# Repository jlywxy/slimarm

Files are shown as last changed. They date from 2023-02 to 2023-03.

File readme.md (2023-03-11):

# SlimARM Boards

The project is aiming to manufacture custom-made boards of ARM processors(specially-designed for specified usage, slim in dimension).<br>

Author: jlywxy(jlywxy@outlook.com)<br>
Document Version: 0.5<br>

- --

## Project Status
```
[ok]SlimARM Classic
----[ok]SlimARM Classic 2410
----[stall]SlimARM Classic 2416
[..]SlimARM Zero
----[..]SlimARM Zero AllWinner A20
----[  ]SlimARM Zero RK3368
[  ]SlimARM Fusion Zynq
```
Note: [..] means work doing.

- --

## Board Specification

* Note 1: see each board design in their directories when board design is done.<br>
* Note 2: all board are designed with proper PCB constraints, even SDR SDRAMs are tuned in length.<br>
* Note 3: for some boards using DDR3, KiCad may also be used for design without proper simulation like Altium/Cadence provided. The design will almost comply to the sigrity stuffs (constraints, impedance) as able when routing to reduce the factor of lack of simulation.
<br>
<br>
<br>
Boards:
* SlimARM Zero<br>
CPU <b>AllWinner A20/Rockchip RK3368</b><br>
A board with minimum ARM requirements with USB, SDIO and Wi-Fi. <br>
This is specified for "On-The-Go" Linux experience similar to the RaspberryPi.<br>

* SlimARM Fusion<br>
CPU <b>Xilinx XC7Z010-1CLG400</b><br>
The board for Linux and calculation acceleration combination usage, the PL part of Zynq 7000s is also fine for LCD display and video processor. It is especially designed for low cost and convenience, picking up only xc7z010 and ft2232hl on board.

* SlimARM Classic (EOL)<br>
CPU <b>Samsung S3C2410AL/S3C2416XH</b><br>
A board with minimum ARM requirements with only USB Device Port extended.<br>
This board is pointing to low cost, replacing the legacy project 'us3c ultra'.<br>
Current cost for SlimARM Classic 2410: 24 RMB approx. (S3C2410: 9, DRAM: 2, NAND: 4, PCB: 6, LDO/Caps/R/Xtals/...: 3 approx.)<br>
<b>Note: This part is EOL and not suitable for new design/manufacture.</b><br>

- --
## Misc
### Board Part-of-Project,SubPart-of-Project to Board-Part-Number maps

Part of Project|Sub Part of Project|Board Part Number
-|-|-
SlimARM Classic|SlimARM Classic 2410|slarm_cls_2410
||SlimARM Classic 2416|slarm_cls_2416
SlimARM Zero|SlimARM Zero AllWinner A20|slarm_z_awa20
||SlimARM Zero RK3368|slarm_z_3368
SlimARM Fusion|SlimARM Fusion Zynq|slarm_f_7z010

---
### Document Patch and Errata
* Changed project plan: SlimARM Zero has changed its CPU from RK3128 to RK3368, which has 0.8mm-pitch BGA for low-cost PCB manufactuing.
* Marked slimarm classic 2410 workaround state.
* Paused the process of part "slimarm classic 2416" due to PCB manufacturing problem taken by 0.65mm-pitch BGA design.<br>

patch above: jlywxy@2023.3.11<br>

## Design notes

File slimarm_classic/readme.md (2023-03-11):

# SlimARM Classic

This part of project is making board for "classic" ARM processors (Samsung S3C2410AL/S3C2416XH).<br>
Although these chips are out-dated in performance, their cost is ever lower than STM32s while having higher performance than them, making them fit for entry-level ARM developments.<br>

Project status:<br>
```
[ok]SlimARM Classic 2410 (slarm_cls_2410_v1r2)
[stall]SlimARM Classic 2416 (slarm_cls_2416)
```

*Warning: The workaround part of linux running on the board is in a stall state. Look into slarm_cls_2410's readme for detail.
- --
## Misc

### Document Patch and Errata
* Marked slimarm classic 2410 workaround state.
* Paused the process of part "slimarm classic 2416" due to PCB manufacturing problem taken by 0.65mm-pitch BGA design.<br>

patch above: jlywxy@2023.3.11<br>

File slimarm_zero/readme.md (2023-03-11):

# SlimARM Zero

This part of project is making board for low-cost Cortex-A ARM processors.<br>

Project status:<br>
```
[..]SlimARM Zero AllWinner A20 (slarm_z_awa20)
[  ]SlimARM Zero RK3368 (slarm_z_3368)
```
- --
## Misc

### Document Patch and Errata
(none)

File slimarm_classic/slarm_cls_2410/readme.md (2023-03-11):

# Slimarm Classic 2410: bare-metal code execution and Linux research on S3C2410AL

This project is making a minimum S3C2410AL core board to run bare-metal code and Linux.
<br><br>
Author: jlywxy(jlywxy@outlook.com)<br>
Document Version: 2.1<br>

- --

## Project Status

```
[ok]pcb manufacturation and verification
[ok]openocd and jtag configurations 
[ok]KeilMDK/IAR toolchain bare-metal code compiling
[ok]openocd connect and debug
[ok]startup assembly explained and general concepts for arm startup sequences
[ok]gnu toolchain bare-metal assembly compiling
[ok]pcb with flash and dram stable version(slimarm classic)
[ok]pcb gerber sharing
[ok]gnu toolchain(arm-none-eabi-) bare-metal c code compiling

[failed]writing simple usb device CDC communication program
[ok]crosstool-ng toolchain on macOS(arm-unknown-linux-gnueabi-) and u-boot compiling
[failed]running Linux onboard, debugging via USBD
```
- --

## Processor Overview

Samsung S3C2410AL-20:<br>
* 16/32-bit(Little Endian) ARM920T RISC Arch
* ARM/Thumb mode
* JTAG debug
* internal 4kB Boot RAM(Steppingstone for NAND flash booting)
* 16kB I-Cache and 16kB D-Cache, MMU
* NAND & SDRAM support
* 1.8v internal voltage supporting max FCLK 200MHz
* on-chip PLL
* watchdog Timer
* 272-FBGA package (0.8mm pitch)
* 3.3v multiplexed I/O ports
* more but not related features...
- --

## S3C2410 Fail Part Problems
The workaround part of linux running on the board is in a stall state, since none of the proper u-boot version is found for s3c2410 to use USB Device as a console interface. u-boot seems never supported s3c2410 USB Device. The transition for UDC codes from linux to u-boot is hard to do. <br>
The fatal problem for USBD unablility is resulting from the board that did not extend any UART ports for u-boot to print debug messages.<br>
Since the processor is too old (in performance and arch) nowadays and <b>lack of support</b>, this part of project is marked with EOL, and not designing and revising new boards with 2410.<br>
<b>The day the usb device stuff is able to run on slimarm classic 2410, only the day the project starts again.</b><br>
As a result, The whole project is putting more attention on those advanced processors, see part SlimARM Zero/Fusion.

- --
## Making the core board for S3C2410

Note: This project is now testing the new designed core board `slimarm classic 2410 v1r1` with:<br>
* 32 MBytes SDRAM(tuned line length)
* 32 MBytes NAND flash(used for nand boot)

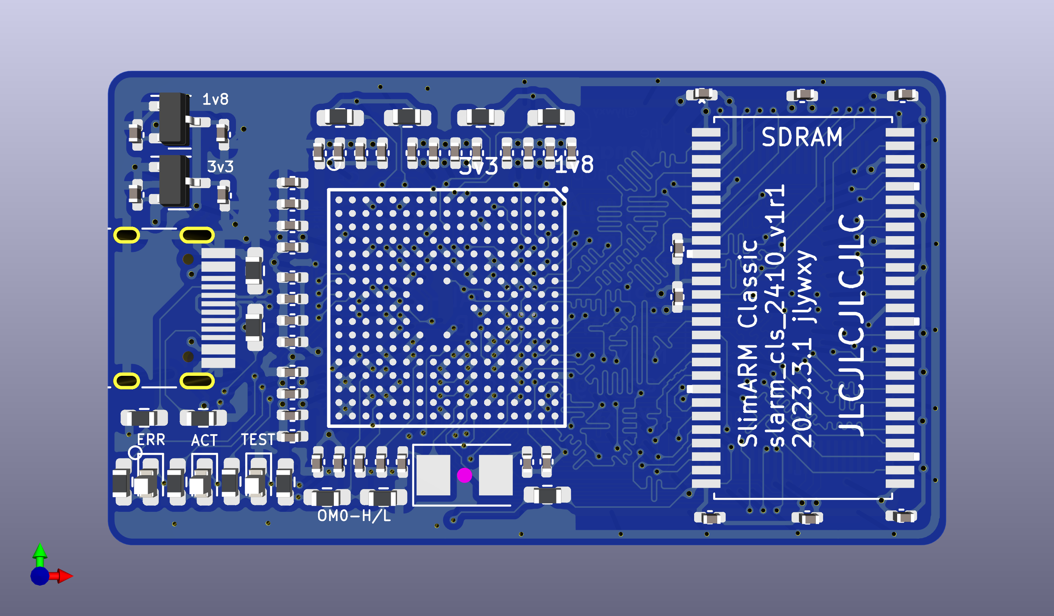
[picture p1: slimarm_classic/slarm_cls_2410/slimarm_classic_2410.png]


PCB Design Suggestions:
1. Make sure pins unwanted has been properly pulled-up or down according to S3C2410 datasheet.
2. When soldering S3C2410 onto the board, use heat gun <b>BELOW 300 C</b> temperature, otherwise the chip will damage.
3. When using 16 bit memory chips, connect chip address line A0 to CPU A1, and so on.
4. Enlarge the width of power lines as it could. Use 2.0v LDO instead of 1.8v LDO.
5. Satifsy "3W" wiring rule everywhere except of BGA area.
6. Make small components the same direction for easy soldering.

For more design points, see <a href="slimarm_classic_2410.md">slimarm_classic_2410.md</a>
- --

## Compiling LED-blinking code using arm-none-eabi- toolchain

1. Writing startup code<br>

* Init interrupt vectors<br>
* Jump to main (function of blinking LED)<br>
```asm
.text
    b _reset
    ldr pc, _undef
    ldr pc, _softir
    ldr pc, _abpre
    ldr pc, _abdat
    ldr pc, _reserved
    ldr pc, _irq
    ldr pc, _fiq
_reset:
    b main
```
https://stackoverflow.com/questions/18848776/what-does-label-word-label-mean-in-arm-assembly<br>

* Init arm modes and stacks(This part is still under working)<br>

Note: when loading 32bit immediate number to register, use `ldr Rn, =0xnum`:<br>
https://developer.arm.com/documentation/dui0473/j/writing-arm-assembly-language/load-32-bit-immediate-values-to-a-register-using-ldr-rd---const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<br>

2. Make and link

```shell
$ arm-none-eabi-as -mcpu=arm920t -o main.o main.s
$ arm-none-eabi-ld -T link.lds -o main.elf main.o
```
Note: the `.text` segment need to be linked to `0x40000000`. The linker script should look like this:<br>
```
SECTIONS {
    . = 0x40000000;
    .text : { * (.text); }
}
```
For the usage of linker script, check http://bravegnu.org/gnu-eprog/lds.html<br>

3. Check compiled executable in assembly and hex<br>
* Use arm-none-eabi-objdump to read startup code and c code assembly.<br>
```shell
$ arm-none-eabi-objdump -D /path/to/elf
```
Note: do not use objdump to read `.comment` section, use readelf instead.<br>
```shell
$ arm-none-eabi-readelf -p .comment /path/to/elf
```
* Use arm-none-eabi-objcopy to convert elf to hex(executable ihex,which represents the real binary stream content stored in memory chips), if another selected flash program is using hex files.<br>
```shell
$ arm-none-eabi-objcopy -O ihex /path/to/elf /path/to/hex
```

- --

## Connecting to the chip
1. This project uses a cheap cloned Altera USB Blaster as a JTAG programmer, because openocd has support for it and S3C2410 do not support SWD.

2. A custom openocd cfg file should be created.
checkout <a href="slimarm_classic_2410.cfg">slimarm_classic_2410.cfg</a>
- --

## Chip Boot Sequence

1. Before NAND takes place, OM[1:0] was set to 01 for not booting from NAND Flash and set Boot RAM bus width to 32bits. Simutaneously the address of Boot RAM is determined to 0x40000000.<br>Otherwise, the Boot RAM is linked to 0x0.
OM[3:2] was set to 00 to use Crystal(12MHz with two 22pF caps) for UPLL and MPLL clock input.

2. the Boot RAM (called as Steppingstone) is a piece of internal RAM region in the chip used for automatically copying boot code in NAND Flash to execute in place, which starts at 0x00000000. If ROM like NOR Flash is used, then the chip also starts at 0x00000000, fetching instructions from NOR directly.

3. When chip was powered on, it starts from Boot RAM or NOR (0x00000000), where interrupt vectors is set. Then it will <b>jump to the label for initializing each arm modes and their stack spaces, disabling IRQs, then environment is ready</b> to execute from c code `main`.<br>
https://developer.arm.com/documentation/dui0471/m/embedded-software-development/stack-pointer-initialization

- -- 

## Uploading compiled code to Boot RAM

1. Start openocd using previous created cfg file, connect to openocd CLI using telnet at port 4444. <br>
Then use openocd "load_image" command as follow:<br>
`load_image /path/to/elf(or axf or hex)`<br>
which means filling Boot RAM with selected program image.

2. start code execution:<br>
`resume 0x40000000`<br><br>
Note: when linker was not setting `.text` segment to correct address at 0x40000000, the program will not work.<br>
Because some of the constants are not calculated correctly based on the `.text` starting address. <br>
For more details, use `arm-none-eabi-objdump -d /path/to/elf` to differ the two compiled executives in <a href="link_problem_example">link_problem_example</a>, in where contains one elf linked `.text` to 0x0 and the other elf linked `.text` to 0x40000000.
In this environment, neither `b/bl :label/#num`,`ldr pc,[pc,#num]` nor `(openocd)resume #num` points real instruction address + 4. Use their real address when branching.

- --

## Misc

<--To Be Continued-->

1. Document Patch and Errata
* Added peripheral operation concepts in "Writing and Compiling code using Keil MDK 5"<br>
* Modified "BootROM" to "Boot RAM" in the whole article.<br>
* Added Boot RAM definition in "S3C2410AL Boot Concepts"<br>
* Added performance test method and knowledge bases in "Misc".<br>
* Added openocd init method and single-line-configuration(with arm machine code explained) in "Uploading compiled code to Boot RAM"<br>
* Corrected single-line-configuration, in which PLL conf command was set to more stable value. Corrected contents of machine code explained.
* Added paragraph "Processor Overview"<br>

patch above: jlywxy@2023.1.19<br>

* Added paragrapg "Project Status"<br>
* Modified "Connecting to the chip".2: added "bindto 0.0.0.0" for IAR remote gdb debug connection.<br>
* Modified "Writing and Compiling code using ~~Keil MDK 5~~ IAR 9" content for IAR usage.<br>
* Implemented "Processor Overview"<br>

patch above: jlywxy@2023.1.25<br>

* Modified Severe Error: in "Uploading compiled code to Boot RAM", after code loaded, openocd resuming from 0x40000000 rather than 0x40000004, which indicates a former linking problem: .text was linked to 0x0 and written to 0x40000000, therefore contents of constant data may be malformed. <br>

errata above: jlywxy@2023.1.26<br>

* Updated project status; adding PCB project files. <br>

patch above: jlywxy@2023.1.28<br>

* Changed the direction of the project.

patch above: jlywxy@2023.1.30<br>

* Modified PCB design problem. <br>
fixed sdram wiring problem; removed nor flash; added sdcard slot.

patch above: jlywxy@2023.2.5<br>

* Committed new PCB design and corrected PCB design points, corrected Chip boot concepts.

patch above: jlywxy@2023.3.1<br>

* Marked slimarm classic 2410 workaround state.

patch above: jlywxy@2023.3.11<br>

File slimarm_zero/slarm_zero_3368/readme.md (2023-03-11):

# SlimArm Zero 3368: The low-cost and slim board act as RaspberryPi

This part of project is making a 6-layer RK3368 standalone core board to run bare-metal code and Linux with a small dimension.
<br><br>
Author: jlywxy(jlywxy@outlook.com)<br>
Document Version: 1.0<br>

- --

## Project Status

```
[..]pcb design
----[  ]Circuit Schematics
----[  ]DDR3 wiring simulation by Candence
[  ]pcb manufacturation and verification
[  ]openocd and jtag configurations 
[  ]openocd connect and debug
[  ]pcb gerber sharing
....
```
- --

## Processor Overview

Rockchip RK3368:<br>
* 8x Cortex A53
* JTAG debug
* Internal 68KB SRAM
* SD/MMC/eMMC/NAND storage support
* DDR3 memory support
* 1.0/1.2/1.5/1.8/2.5/3.3 Voltage, DVFS
* on-chip PLL up to 2.2GHz
* TFBGA453 package <b>(0.8mm pitch)</b>
* more but not related features...
- --

<-- To Be Continued -->

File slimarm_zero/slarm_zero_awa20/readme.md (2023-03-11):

# SlimArm Zero AllWinner-A20: The low-cost and slim board act as RaspberryPi

This part of project is making a 4-layer AllWinner A20 standalone core board to run bare-metal code and Linux with a small dimension.
<br><br>
Author: jlywxy(jlywxy@outlook.com)<br>
Document Version: 1.0<br>

- --

## Project Status

```
[..]pcb design
----[..]Circuit Schematics
----[..]DDR3 wiring simulation by KiCad
[  ]pcb manufacturation and verification
[  ]openocd and jtag configurations 
[  ]openocd connect and debug
[  ]pcb gerber sharing
....
```
- --

## Processor Overview

AllWinner A20:<br>
* 2x Cortex A7
* JTAG debug
* SD/MMC/eMMC/NAND storage support
* DDR3 memory support
* 1.3/1.8/2.5/3.3 Voltage, DVFS
* on-chip PLL
* FBGA441 package <b>(0.8mm pitch)</b>
* more but not related features...
- --

<-- To Be Continued -->

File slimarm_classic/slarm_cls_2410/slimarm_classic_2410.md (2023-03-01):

# SlimARM Classic 2410 v1r1 PCB layout points

## PCB constraints

1. 4-layers
2. Line width: 3.5 mils
3. Line to Line/Via: 5+ mils
4. Minimum Via Diameter: 18 mils/10 mils

## BOM
```
Part No.                Package     Usage               Memory-Features     Brand      Comments

--Chip Components--
1. S3C2410AL-20:        FBGA272,    Main Processor,     4kB-SRAM            Samsung     3.3v+1.8v
2. HY57V561620FTP-H:    TSOPII54,   SDRAM,              32MB                Hynix       3.3v
3. K9F5608U0*:          TSOP48,     NAND Flash,         32MB                Samsung     3.3v
   MT29F1G08*           TSOP48,     NAND Flash,         128MB               Micron      3.3v

--Power Supply, Crystal, Connector Components--
1. XC6206:              SOT-23,     LDO,                -                   (Any)
2. (Any):               5032,       12MHz Crystal,      -                   (Any)       (with 22pF capacitors)
3. (Any):               USB-C-16p,  USB-C Connector,    -                   (Any)
```

## Wiring Notice

```
1. Cystal             12MHz + 22pF capacitor
2. EXTCLK             Pull-up (Not using EXTCLK)
3. nBATT_FLT          Pull-up (Not using Battery)
4. OM[3,2,1]          Pull-down (Not using EXTCLK)
5. JTAG               Pull-up(10k)
6. USB CC             Pull-down(5.1k)
7. USB DP/DN          Pull-up(1.5k)/down(470k)
8. OM[0]              Jumpwire (NANDboot: 0)
9. Bus nWAIT          Pull-up (Not using nWAIT)
110 USB Impedance     90(Diff)/45(Single)
```

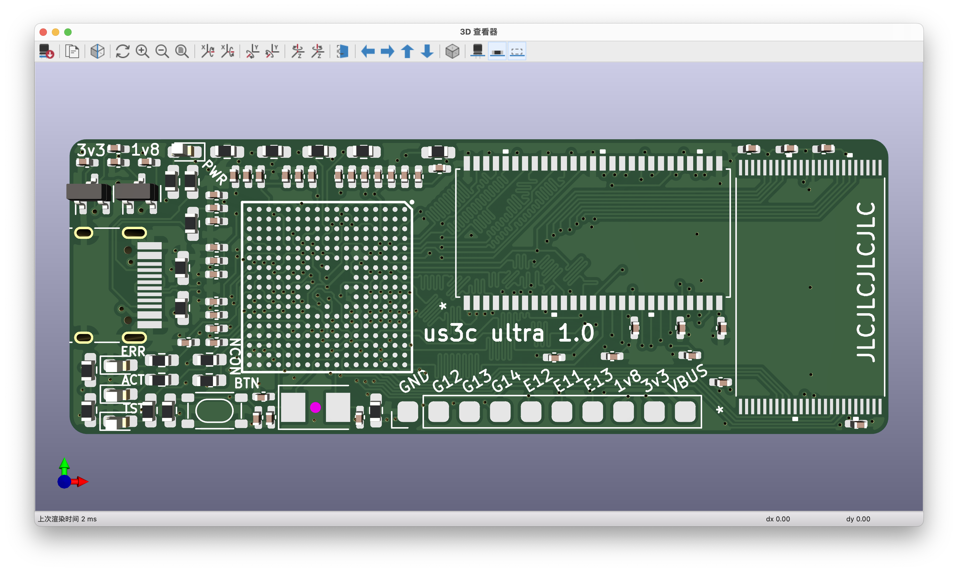
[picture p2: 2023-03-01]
slimarm_classic/slarm_cls_2410/misc/截屏2023-02-06 17.06.20.png

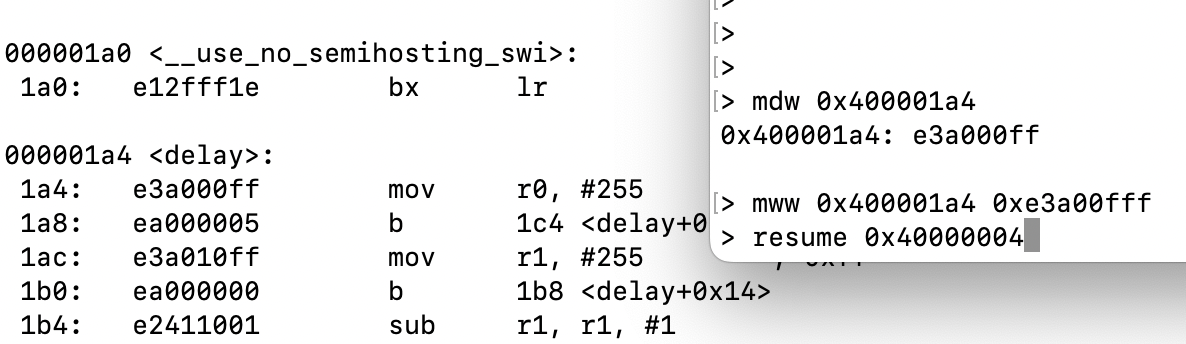
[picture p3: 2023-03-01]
slimarm_classic/slarm_cls_2410/misc/截屏2023-01-19 12.25.58.png

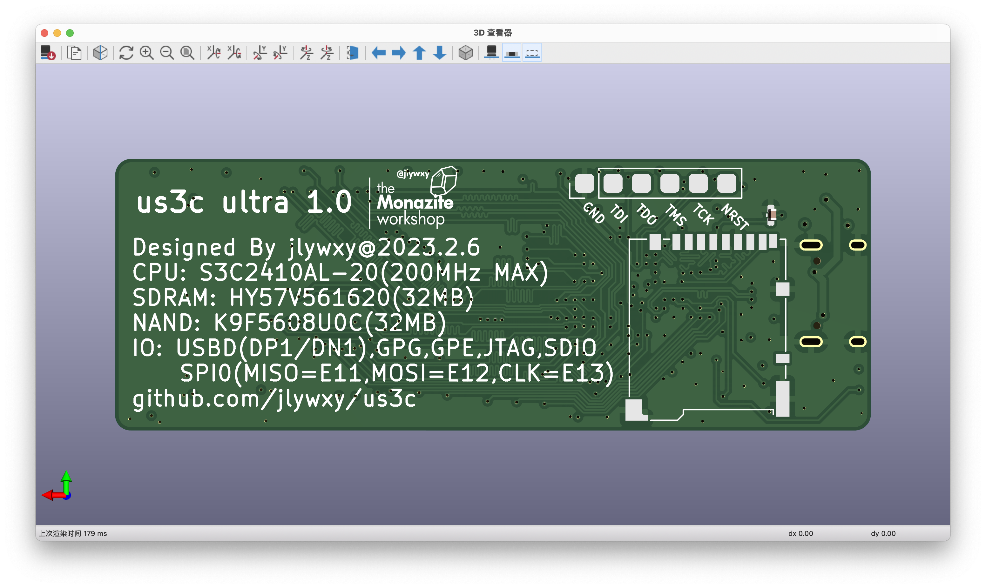
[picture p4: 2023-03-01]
slimarm_classic/slarm_cls_2410/misc/截屏2023-02-06 17.02.37.png

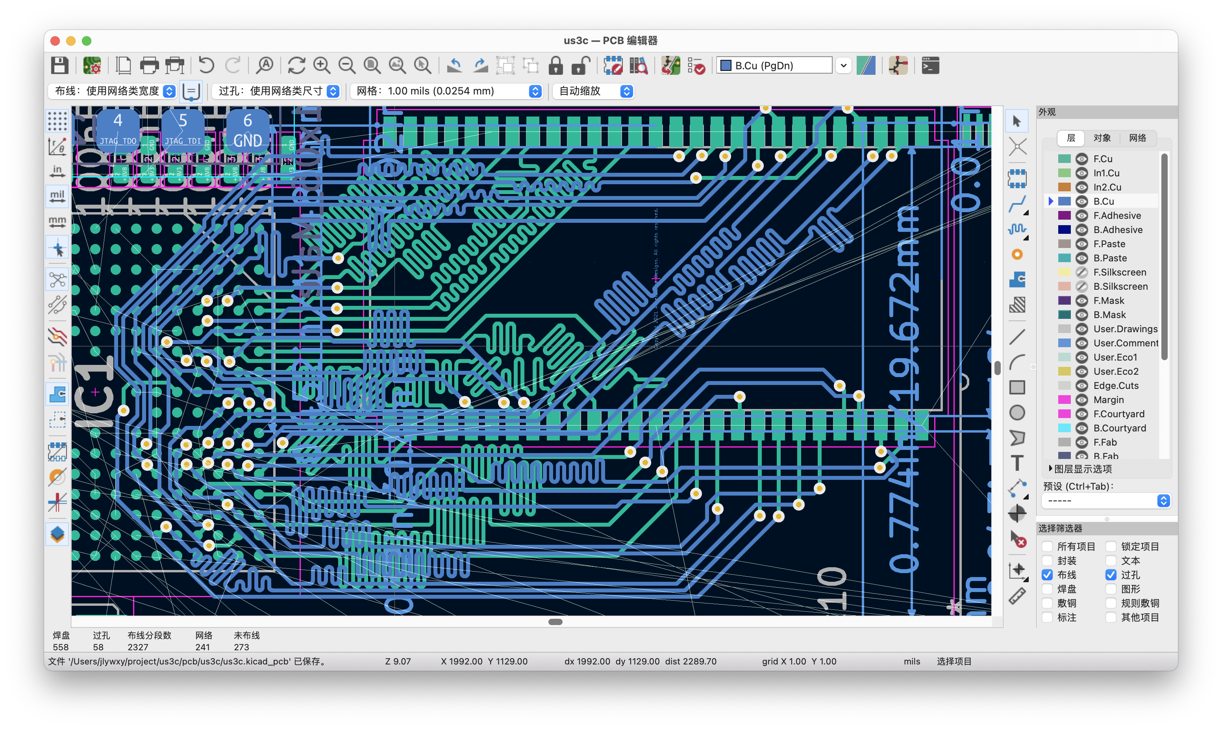
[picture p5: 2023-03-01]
slimarm_classic/slarm_cls_2410/misc/截屏2023-02-05 15.36.12.png

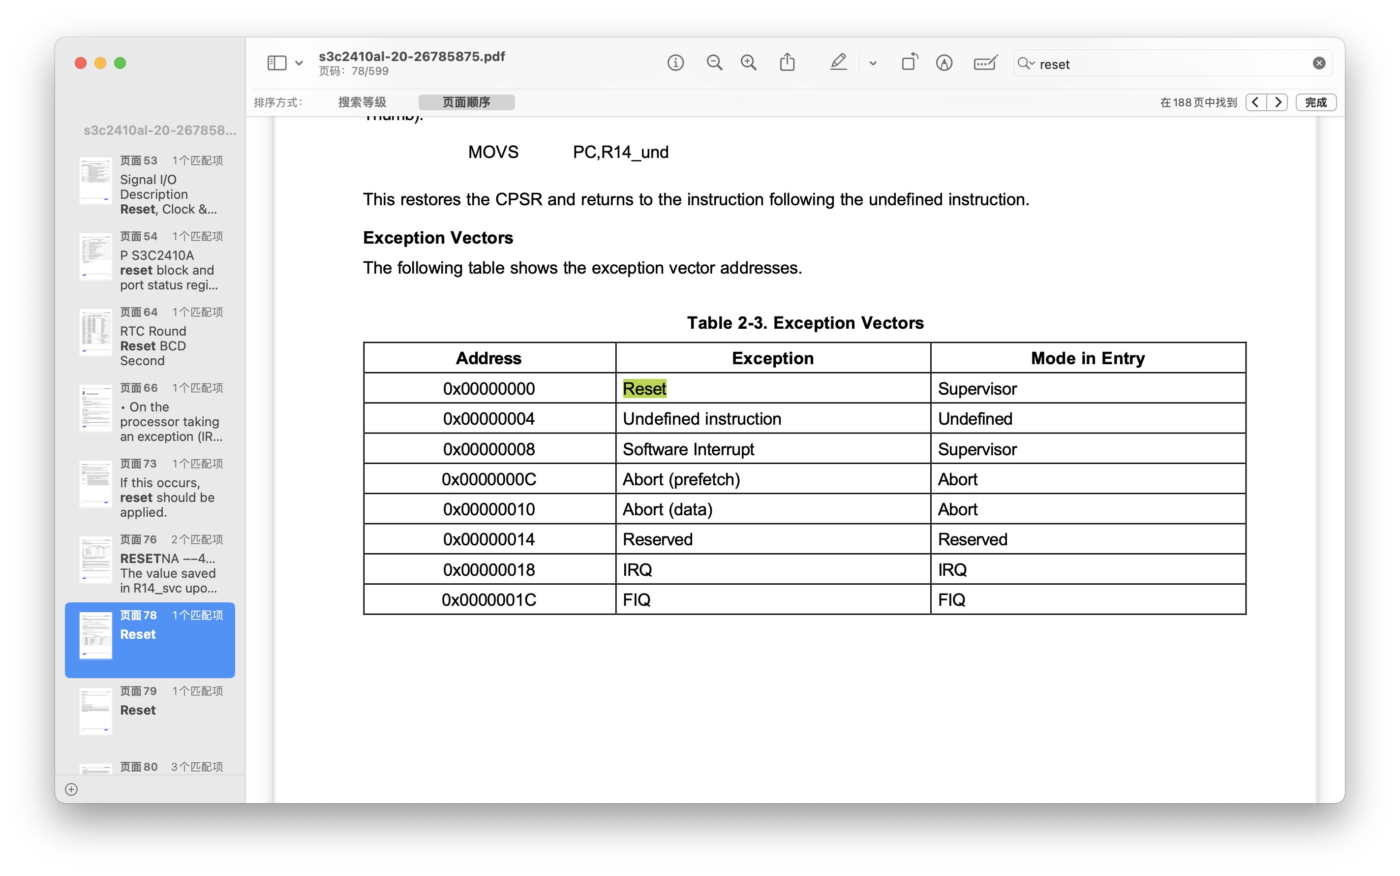
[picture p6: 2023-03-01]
slimarm_classic/slarm_cls_2410/misc/截屏2023-01-25 16.31.00.png

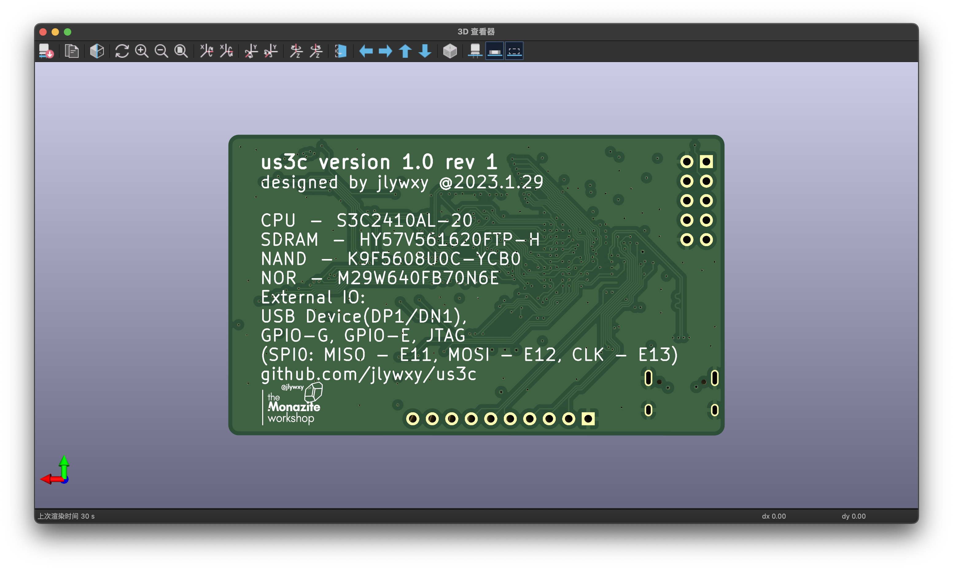
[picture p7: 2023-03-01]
slimarm_classic/slarm_cls_2410/misc/截屏2023-01-29 00.44.54.png

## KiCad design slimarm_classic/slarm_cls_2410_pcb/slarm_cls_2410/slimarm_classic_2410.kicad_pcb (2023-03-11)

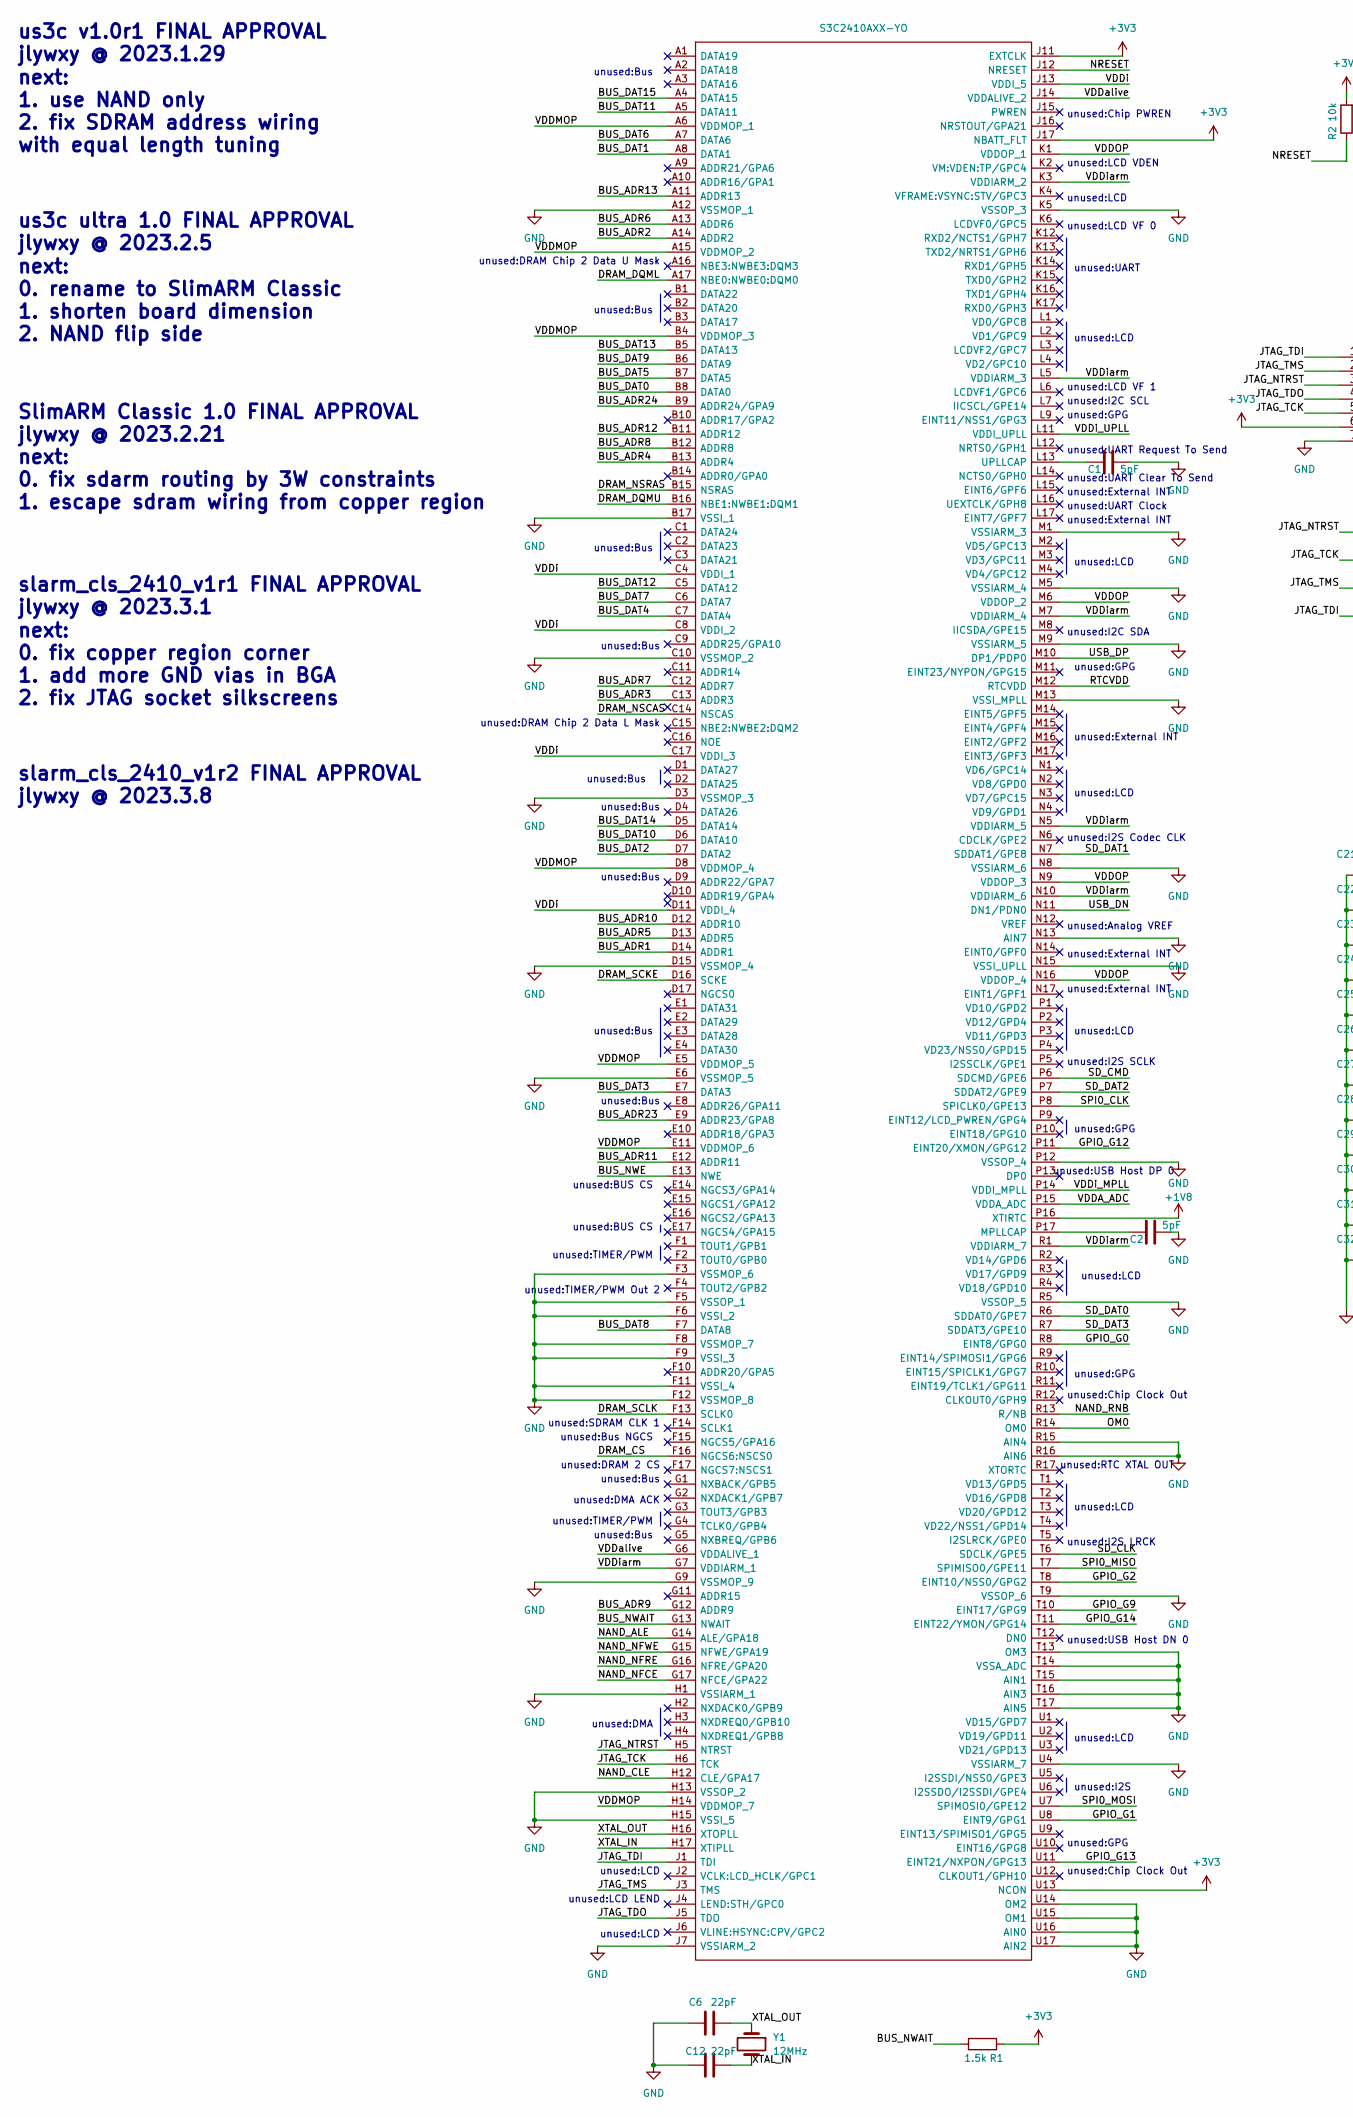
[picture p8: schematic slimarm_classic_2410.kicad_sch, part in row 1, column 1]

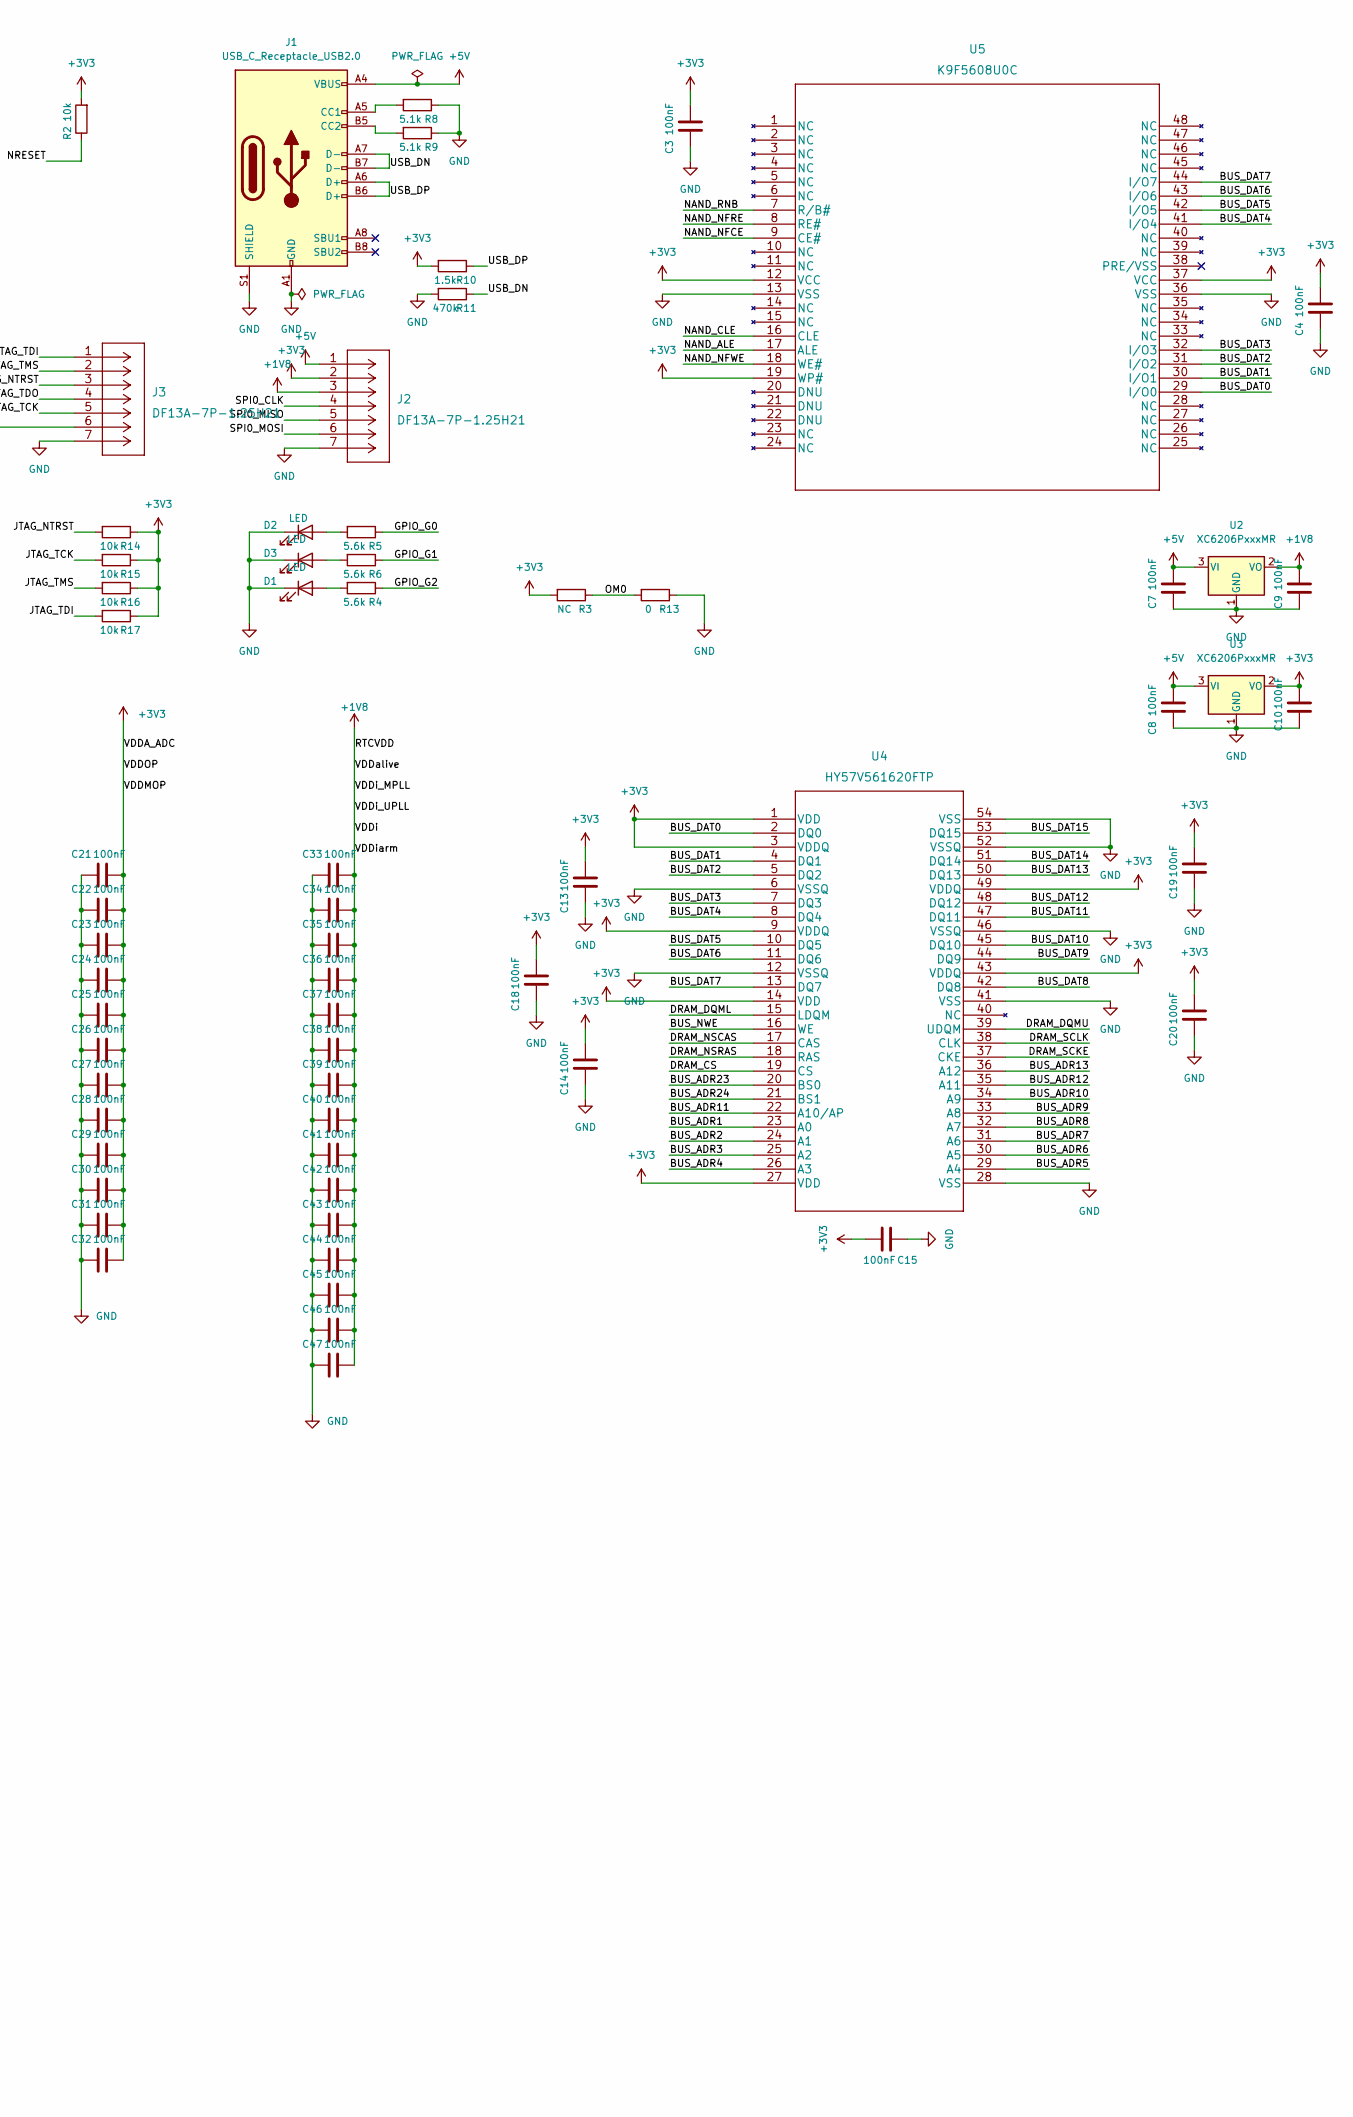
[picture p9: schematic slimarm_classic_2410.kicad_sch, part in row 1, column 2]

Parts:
C1, C2: 5pF; C_0402_1005Metric_Pad0.74x0.62mm_HandSolder
C3, C4, C7, C8, C9, C10, C13, C14, C15, C18, C19, C20, C21, C22, C23, C24, C25, C26, C27, C28, C29, C30, C31, C32, C33, C34, C35, C36, C37, C38, C39, C40, C41, C42, C43, C44, C45, C46, C47: 100nF; C_0402_1005Metric_Pad0.74x0.62mm_HandSolder
C6, C12: 22pF; C_0402_1005Metric_Pad0.74x0.62mm_HandSolder
D1, D2, D3: LED; LED_0603_1608Metric_Pad1.05x0.95mm_HandSolder
IC1: S3C2410AXX-YO; BGA272C80P17X17_1400X1400X116; Manufacturer_Part_Number S3C2410AXX-YO
J1: USB_C_Receptacle_USB2.0; USB_C_Receptacle_HRO_TYPE-C-31-M-12
J2, J3: DF13A-7P-1.25H21
R1, R10: 1.5k; R_0603_1608Metric_Pad0.98x0.95mm_HandSolder
R2, R14, R15, R16, R17: 10k; R_0603_1608Metric_Pad0.98x0.95mm_HandSolder
R3: NC; R_0603_1608Metric_Pad0.98x0.95mm_HandSolder
R4, R5, R6: 5.6k; R_0603_1608Metric_Pad0.98x0.95mm_HandSolder
R8, R9: 5.1k; R_0603_1608Metric_Pad0.98x0.95mm_HandSolder
R11: 470k; R_0603_1608Metric_Pad0.98x0.95mm_HandSolder
R13: 0; R_0603_1608Metric_Pad0.98x0.95mm_HandSolder
U2, U3: XC6206PxxxMR; SOT-23
U4: HY57V561620FTP
U5: K9F5608U0C; M29W640FB70N6E
Y1: 12MHz; Crystal_SMD_5032-2Pin_5.0x3.2mm

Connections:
+1V8: C9.2, C33.2, C34.2, C35.2, C36.2, C37.2, C38.2, C39.2, C40.2, C41.2, C42.2, C43.2, C44.2, C45.2, C46.2, C47.2, IC1.C4 (VDDI_1), IC1.C8 (VDDI_2), IC1.C17 (VDDI_3), IC1.D11 (VDDI_4), IC1.G6 (VDDALIVE_1), IC1.G7 (VDDIARM_1), IC1.J13 (VDDI_5), IC1.J14 (VDDALIVE_2), IC1.K3 (VDDIARM_2), IC1.L5 (VDDIARM_3), IC1.L11 (VDDI_UPLL), IC1.M7 (VDDIARM_4), IC1.M12 (RTCVDD), IC1.N5 (VDDIARM_5), IC1.N10 (VDDIARM_6), IC1.P14 (VDDI_MPLL), IC1.P16 (XTIRTC), IC1.R1 (VDDIARM_7), J2.3, U2.2 (VO)
+3V3: C3.2, C4.2, C10.2, C13.2, C14.2, C15.2, C18.2, C19.2, C20.2, C21.2, C22.2, C23.2, C24.2, C25.2, C26.2, C27.2, C28.2, C29.2, C30.2, C31.2, C32.2, IC1.A6 (VDDMOP_1), IC1.A15 (VDDMOP_2), IC1.B4 (VDDMOP_3), IC1.D8 (VDDMOP_4), IC1.E5 (VDDMOP_5), IC1.E11 (VDDMOP_6), IC1.H14 (VDDMOP_7), IC1.J11 (EXTCLK), IC1.J17 (NBATT_FLT), IC1.K1 (VDDOP_1), IC1.M6 (VDDOP_2), IC1.N9 (VDDOP_3), IC1.N16 (VDDOP_4), IC1.P15 (VDDA_ADC), IC1.U13 (NCON), J2.2, J3.6, R1.1, R2.2, R3.2, R10.2, R14.1, R15.1, R16.1, R17.1, U3.2 (VO), U4.1 (VDD), U4.3 (VDDQ), U4.9 (VDDQ), U4.14 (VDD), U4.27 (VDD), U4.43 (VDDQ), U4.49 (VDDQ), U5.12 (VCC), U5.19 (WP#), U5.37 (VCC)
+5V: C7.2, C8.2, J1.A4 (VBUS), J1.A9 (VBUS), J1.B4 (VBUS), J1.B9 (VBUS), J2.1, U2.3 (VI), U3.3 (VI)
/BUS_ADR1: IC1.D14 (ADDR1), U4.23 (A0)
/BUS_ADR2: IC1.A14 (ADDR2), U4.24 (A1)
/BUS_ADR3: IC1.C13 (ADDR3), U4.25 (A2)
/BUS_ADR4: IC1.B13 (ADDR4), U4.26 (A3)
/BUS_ADR5: IC1.D13 (ADDR5), U4.29 (A4)
/BUS_ADR6: IC1.A13 (ADDR6), U4.30 (A5)
/BUS_ADR7: IC1.C12 (ADDR7), U4.31 (A6)
/BUS_ADR8: IC1.B12 (ADDR8), U4.32 (A7)
/BUS_ADR9: IC1.G12 (ADDR9), U4.33 (A8)
/BUS_ADR10: IC1.D12 (ADDR10), U4.34 (A9)
/BUS_ADR11: IC1.E12 (ADDR11), U4.22 (A10/AP)
/BUS_ADR12: IC1.B11 (ADDR12), U4.35 (A11)
/BUS_ADR13: IC1.A11 (ADDR13), U4.36 (A12)
/BUS_ADR23: IC1.E9 (ADDR23/GPA8), U4.20 (BS0)
/BUS_ADR24: IC1.B9 (ADDR24/GPA9), U4.21 (BS1)
/BUS_DAT0: IC1.B8 (DATA0), U4.2 (DQ0), U5.29 (I/O0)
/BUS_DAT1: IC1.A8 (DATA1), U4.4 (DQ1), U5.30 (I/O1)
/BUS_DAT2: IC1.D7 (DATA2), U4.5 (DQ2), U5.31 (I/O2)
/BUS_DAT3: IC1.E7 (DATA3), U4.7 (DQ3), U5.32 (I/O3)
/BUS_DAT4: IC1.C7 (DATA4), U4.8 (DQ4), U5.41 (I/O4)
/BUS_DAT5: IC1.B7 (DATA5), U4.10 (DQ5), U5.42 (I/O5)
/BUS_DAT6: IC1.A7 (DATA6), U4.11 (DQ6), U5.43 (I/O6)
/BUS_DAT7: IC1.C6 (DATA7), U4.13 (DQ7), U5.44 (I/O7)
/BUS_DAT8: IC1.F7 (DATA8), U4.42 (DQ8)
/BUS_DAT9: IC1.B6 (DATA9), U4.44 (DQ9)
/BUS_DAT10: IC1.D6 (DATA10), U4.45 (DQ10)
/BUS_DAT11: IC1.A5 (DATA11), U4.47 (DQ11)
/BUS_DAT12: IC1.C5 (DATA12), U4.48 (DQ12)
/BUS_DAT13: IC1.B5 (DATA13), U4.50 (DQ13)
/BUS_DAT14: IC1.D5 (DATA14), U4.51 (DQ14)
/BUS_DAT15: IC1.A4 (DATA15), U4.53 (DQ15)
/BUS_NWAIT: IC1.G13 (NWAIT), R1.2
/BUS_NWE: IC1.E13 (NWE), U4.16 (WE)
/DRAM_CS: IC1.F16 (NGCS6:NSCS0), U4.19 (CS)
/DRAM_DQML: IC1.A17 (NBE0:NWBE0:DQM0), U4.15 (LDQM)
/DRAM_DQMU: IC1.B16 (NBE1:NWBE1:DQM1), U4.39 (UDQM)
/DRAM_NSCAS: IC1.C14 (NSCAS), U4.17 (CAS)
/DRAM_NSRAS: IC1.B15 (NSRAS), U4.18 (RAS)
/DRAM_SCKE: IC1.D16 (SCKE), U4.37 (CKE)
/DRAM_SCLK: IC1.F13 (SCLK0), U4.38 (CLK)
/GPIO_G0: IC1.R8 (EINT8/GPG0), R5.1
/GPIO_G1: IC1.U8 (EINT9/GPG1), R6.1
/GPIO_G2: IC1.T8 (EINT10/NSS0/GPG2), R4.1
/GPIO_G9: IC1.T10 (EINT17/GPG9)
/GPIO_G12: IC1.P11 (EINT20/XMON/GPG12)
/GPIO_G13: IC1.U11 (EINT21/NXPON/GPG13)
/GPIO_G14: IC1.T11 (EINT22/YMON/GPG14)
/JTAG_NTRST: IC1.H5 (NTRST), J3.3, R14.2
/JTAG_TCK: IC1.H6 (TCK), J3.5, R15.2
/JTAG_TDI: IC1.J1 (TDI), J3.1, R17.2
/JTAG_TDO: IC1.J5 (TDO), J3.4
/JTAG_TMS: IC1.J3 (TMS), J3.2, R16.2
/NAND_ALE: IC1.G14 (ALE/GPA18), U5.17 (ALE)
/NAND_CLE: IC1.H12 (CLE/GPA17), U5.16 (CLE)
/NAND_NFCE: IC1.G17 (NFCE/GPA22), U5.9 (CE#)
/NAND_NFRE: IC1.G16 (NFRE/GPA20), U5.8 (RE#)
/NAND_NFWE: IC1.G15 (NFWE/GPA19), U5.18 (WE#)
/NAND_RNB: IC1.R13 (R/NB), U5.7 (R/B#)
/NRESET: IC1.J12 (NRESET), R2.1
/OM0: IC1.R14 (OM0), R3.1, R13.2
/SD_CLK: IC1.T6 (SDCLK/GPE5)
/SD_CMD: IC1.P6 (SDCMD/GPE6)
/SD_DAT0: IC1.R6 (SDDAT0/GPE7)
/SD_DAT1: IC1.N7 (SDDAT1/GPE8)
/SD_DAT2: IC1.P7 (SDDAT2/GPE9)
/SD_DAT3: IC1.R7 (SDDAT3/GPE10)
/SPI0_CLK: IC1.P8 (SPICLK0/GPE13), J2.4
/SPI0_MISO: IC1.T7 (SPIMISO0/GPE11), J2.5
/SPI0_MOSI: IC1.U7 (SPIMOSI0/GPE12), J2.6
/USB_DN: IC1.N11 (DN1/PDN0), J1.A7 (D-), J1.B7 (D-), R11.1
/USB_DP: IC1.M10 (DP1/PDP0), J1.A6 (D+), J1.B6 (D+), R10.1
/XTAL_IN: C12.2, IC1.H17 (XTIPLL), Y1.2
/XTAL_OUT: C6.2, IC1.H16 (XTOPLL), Y1.1
GND: C1.2, C2.2, C3.1, C4.1, C6.1, C7.1, C8.1, C9.1, C10.1, C12.1, C13.1, C14.1, C15.1, C18.1, C19.1, C20.1, C21.1, C22.1, C23.1, C24.1, C25.1, C26.1, C27.1, C28.1, C29.1, C30.1, C31.1, C32.1, C33.1, C34.1, C35.1, C36.1, C37.1, C38.1, C39.1, C40.1, C41.1, C42.1, C43.1, C44.1, C45.1, C46.1, C47.1, D1.1 (K), D2.1 (K), D3.1 (K), IC1.A12 (VSSMOP_1), IC1.B17 (VSSI_1), IC1.C10 (VSSMOP_2), IC1.D3 (VSSMOP_3), IC1.D15 (VSSMOP_4), IC1.E6 (VSSMOP_5), IC1.F3 (VSSMOP_6), IC1.F5 (VSSOP_1), IC1.F6 (VSSI_2), IC1.F8 (VSSMOP_7), IC1.F9 (VSSI_3), IC1.F11 (VSSI_4), IC1.F12 (VSSMOP_8), IC1.G9 (VSSMOP_9), IC1.H1 (VSSIARM_1), IC1.H13 (VSSOP_2), IC1.H15 (VSSI_5), IC1.J7 (VSSIARM_2), IC1.K5 (VSSOP_3), IC1.M1 (VSSIARM_3), IC1.M5 (VSSIARM_4), IC1.M9 (VSSIARM_5), IC1.M13 (VSSI_MPLL), IC1.N8 (VSSIARM_6), IC1.N13 (AIN7), IC1.N15 (VSSI_UPLL), IC1.P12 (VSSOP_4), IC1.R5 (VSSOP_5), IC1.R15 (AIN4), IC1.R16 (AIN6), IC1.T9 (VSSOP_6), IC1.T13 (OM3), IC1.T14 (VSSA_ADC), IC1.T15 (AIN1), IC1.T16 (AIN3), IC1.T17 (AIN5), IC1.U4 (VSSIARM_7), IC1.U14 (OM2), IC1.U15 (OM1), IC1.U16 (AIN0), IC1.U17 (AIN2), J1.A1 (GND), J1.A12 (GND), J1.B1 (GND), J1.B12 (GND), J1.S1 (SHIELD), J2.7, J3.7, R8.1, R9.1, R11.2, R13.1, U2.1 (GND), U3.1 (GND), U4.6 (VSSQ), U4.12 (VSSQ), U4.28 (VSS), U4.41 (VSS), U4.46 (VSSQ), U4.52 (VSSQ), U4.54 (VSS), U5.13 (VSS), U5.36 (VSS)
unnamed: C1.1, IC1.L13 (UPLLCAP)
unnamed: C2.1, IC1.P17 (MPLLCAP)
unnamed: D1.2 (A), R4.2
unnamed: D2.2 (A), R5.2
unnamed: D3.2 (A), R6.2
unnamed: J1.A5 (CC1), R8.2
unnamed: J1.B5 (CC2), R9.2

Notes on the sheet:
unused:DRAM Chip 2 Data U Mask
unused:DRAM Chip 2 Data L Mask
unused:Bus
unused:TIMER/PWM Out 2
unused:I2S LRCK
unused:LCD
unused:UART
slarm_cls_2410_v1r2 FINAL APPROVAL jlywxy @ 2023.3.8
unused:UART Clear To Send
next: 0. fix copper region corner 1. add more GND vias in BGA 2. fix JTAG socket silkscreens
unused:External INT
unused:DRAM 2 CS
unused:GPG
slarm_cls_2410_v1r1 FINAL APPROVAL jlywxy @ 2023.3.1
unused:RTC XTAL OUT
unused:LCD VF 0
unused:I2S
unused:Chip Clock Out
unused:USB Host DN 0
unused:LCD LEND
unused:LCD VF 1
unused:LCD VDEN
unused:I2C SCL
unused:TIMER/PWM
unused:BUS CS
unused:Chip Clock Out
unused:I2S Codec CLK
unused:USB Host DP 0
unused:DMA ACK
unused:Chip PWREN
next: 0. rename to SlimARM Classic 1. shorten board dimension 2. NAND flip side
unused:UART Request To Send
us3c ultra 1.0 FINAL APPROVAL jlywxy @ 2023.2.5
unused:Bus NGCS
unused:I2S SCLK
unused:SDRAM CLK 1
next: 1. use NAND only 2. fix SDRAM address wiring with equal length tuning
unused:DMA
SlimARM Classic 1.0 FINAL APPROVAL jlywxy @ 2023.2.21 next: 0. fix sdarm routing by 3W constraints 1. escape sdram wiring from copper region
unused:I2C SDA

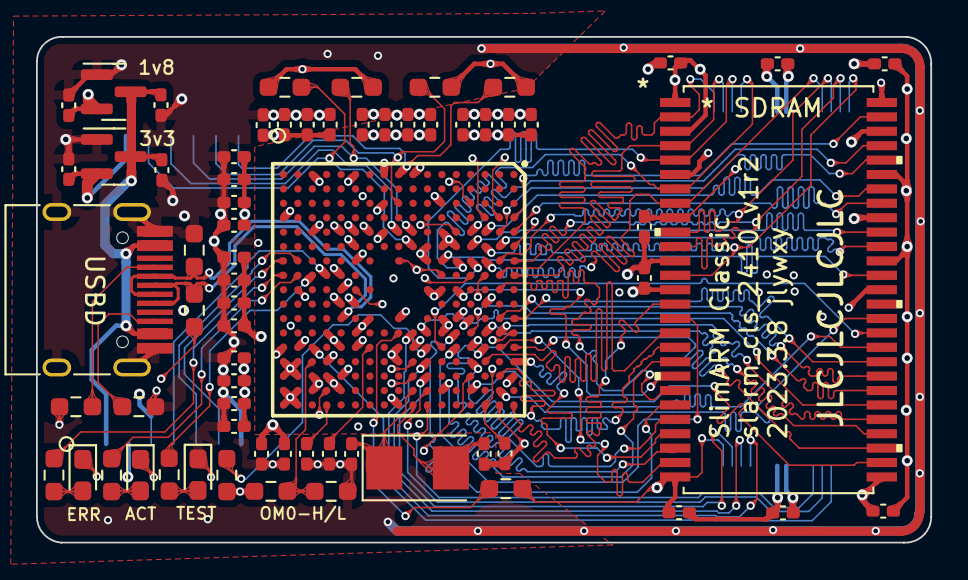
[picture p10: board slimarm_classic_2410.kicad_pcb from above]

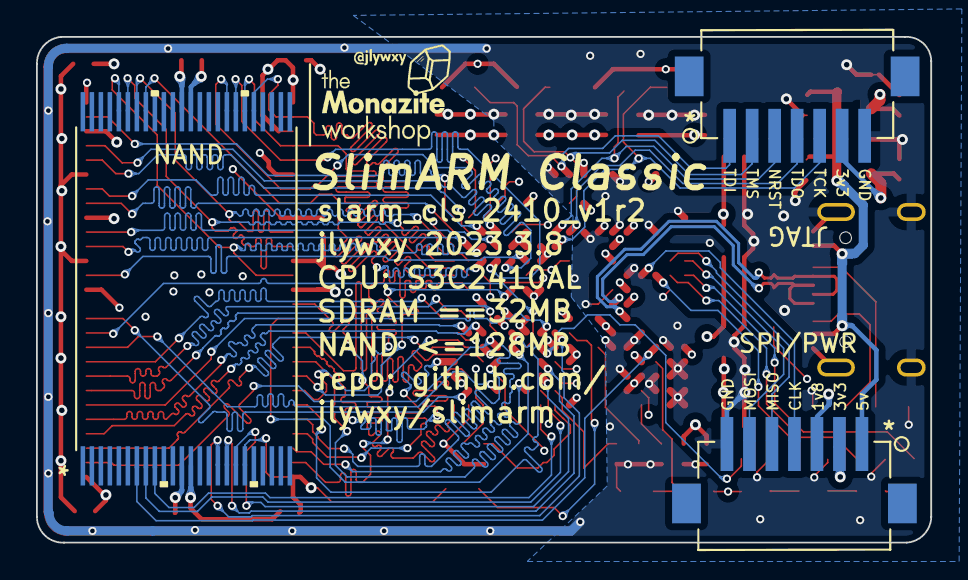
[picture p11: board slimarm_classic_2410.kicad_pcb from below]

Board: 4 copper layers, 49.7 x 28.1 mm, 70 parts (3 on the bottom side), 74 nets.

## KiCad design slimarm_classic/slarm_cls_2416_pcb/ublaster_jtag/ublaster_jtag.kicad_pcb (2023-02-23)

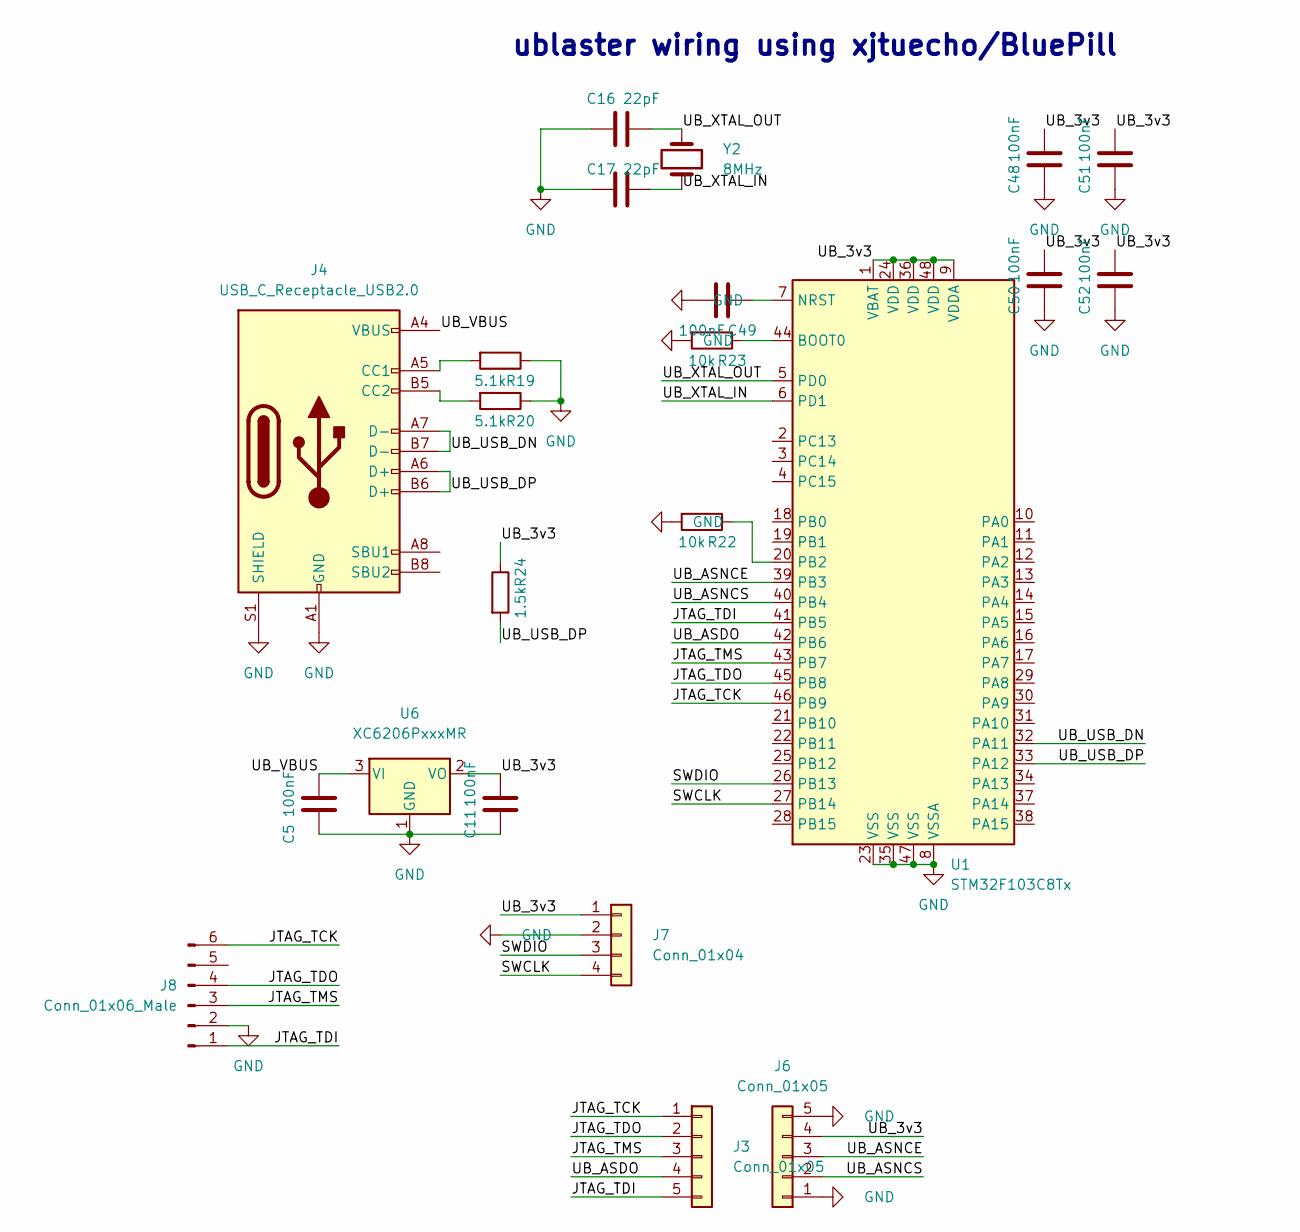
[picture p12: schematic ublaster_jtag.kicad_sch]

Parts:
C5, C11, C48, C49, C50, C51, C52: 100nF; C_0402_1005Metric_Pad0.74x0.62mm_HandSolder
C16, C17: 22pF; C_0402_1005Metric_Pad0.74x0.62mm_HandSolder
J3, J6: Conn_01x05; PinHeader_1x05_P2.54mm_Vertical
J4: USB_C_Receptacle_USB2.0; USB_C_Receptacle_HRO_TYPE-C-31-M-12
J7: Conn_01x04; PinHeader_1x04_P2.54mm_Vertical
J8: Conn_01x06_Male; PinSocket_2x03_P2.00mm_Vertical_SMD
R19, R20: 5.1k; R_0603_1608Metric_Pad0.98x0.95mm_HandSolder
R22, R23: 10k; R_0603_1608Metric_Pad0.98x0.95mm_HandSolder
R24: 1.5k; R_0603_1608Metric_Pad0.98x0.95mm_HandSolder
U1: STM32F103C8Tx; LQFP-48_7x7mm_P0.5mm
U6: XC6206PxxxMR; SOT-23
Y2: 8MHz; Crystal_SMD_5032-2Pin_5.0x3.2mm

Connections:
/JTAG_TCK: J3.1, J8.6, U1.46 (PB9)
/JTAG_TDI: J3.5, J8.1, U1.41 (PB5)
/JTAG_TDO: J3.2, J8.4, U1.45 (PB8)
/JTAG_TMS: J3.3, J8.3, U1.43 (PB7)
/SWCLK: J7.4, U1.27 (PB14)
/SWDIO: J7.3, U1.26 (PB13)
/UB_3v3: C11.2, C48.2, C50.2, C51.2, C52.2, J6.4, J7.1, R24.1, U1.1 (VBAT), U1.9 (VDDA), U1.24 (VDD), U1.36 (VDD), U1.48 (VDD), U6.2 (VO)
/UB_ASDO: J3.4, U1.42 (PB6)
/UB_ASNCE: J6.3, U1.39 (PB3)
/UB_ASNCS: J6.2, U1.40 (PB4)
/UB_USB_DN: J4.A7 (D-), J4.B7 (D-), U1.32 (PA11)
/UB_USB_DP: J4.A6 (D+), J4.B6 (D+), R24.2, U1.33 (PA12)
/UB_VBUS: C5.2, J4.A4 (VBUS), J4.A9 (VBUS), J4.B4 (VBUS), J4.B9 (VBUS), U6.3 (VI)
/UB_XTAL_IN: C17.2, U1.6 (PD1), Y2.2
/UB_XTAL_OUT: C16.2, U1.5 (PD0), Y2.1
GND: C5.1, C11.1, C16.1, C17.1, C48.1, C49.2, C50.1, C51.1, C52.1, J4.A1 (GND), J4.A12 (GND), J4.B1 (GND), J4.B12 (GND), J4.S1 (SHIELD), J6.1, J6.5, J7.2, J8.2, R19.1, R20.1, R22.2, R23.2, U1.8 (VSSA), U1.23 (VSS), U1.35 (VSS), U1.47 (VSS), U6.1 (GND)
unnamed: C49.1, U1.7 (NRST)
unnamed: J4.A5 (CC1), R19.2
unnamed: J4.B5 (CC2), R20.2
unnamed: R22.1, U1.20 (PB2)
unnamed: R23.1, U1.44 (BOOT0)

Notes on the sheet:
ublaster wiring using xjtuecho/BluePill

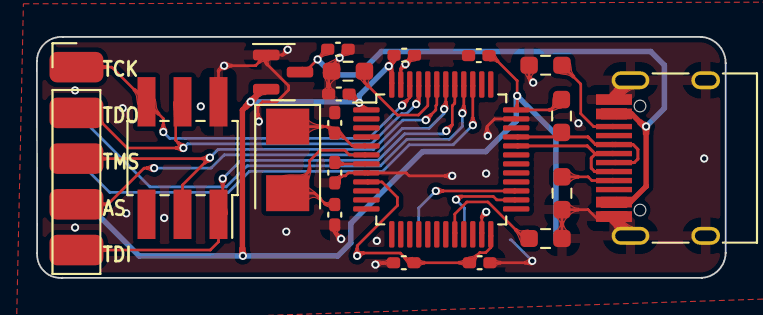
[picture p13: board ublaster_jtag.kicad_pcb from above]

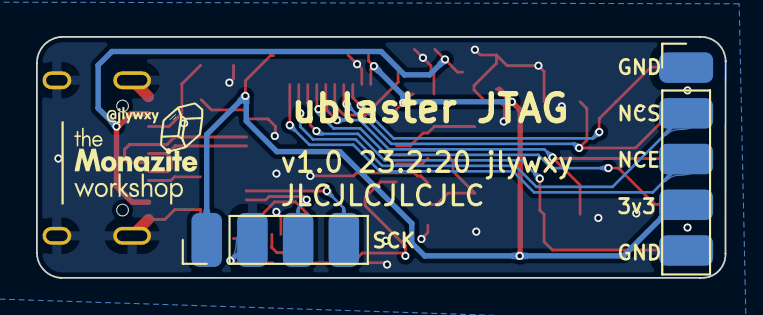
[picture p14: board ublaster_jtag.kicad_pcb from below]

Board: 2 copper layers, 38.3 x 13.4 mm, 22 parts (2 on the bottom side), 21 nets.

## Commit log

2023-02-15 init commit
    [us3c-B_Cu.gbl, us3c-B_Mask.gbs, us3c-B_Paste.gbp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]
2023-02-16 changing plan
    [us3c-B_Cu.gbl, us3c-B_Mask.gbs, us3c-B_Paste.gbp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]
2023-02-23 project status update
    [slimarm_classic-B_Cu.gbl, slimarm_classic-B_Mask.gbs, slimarm_classic-B_Paste.gbp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]
2023-03-01 project plan update
    [slimarm_classic-B_Cu.gbl, slimarm_classic-B_Mask.gbs, slimarm_classic-B_Paste.gbp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]
2023-03-11 new project plan; slarm_cls_2410 board
    [slimarm_classic_2410-B_Cu.gbl, slimarm_classic_2410-B_Mask.gbs, slimarm_classic_2410-B_Paste.gbp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]

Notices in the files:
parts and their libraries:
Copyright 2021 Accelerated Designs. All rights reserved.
